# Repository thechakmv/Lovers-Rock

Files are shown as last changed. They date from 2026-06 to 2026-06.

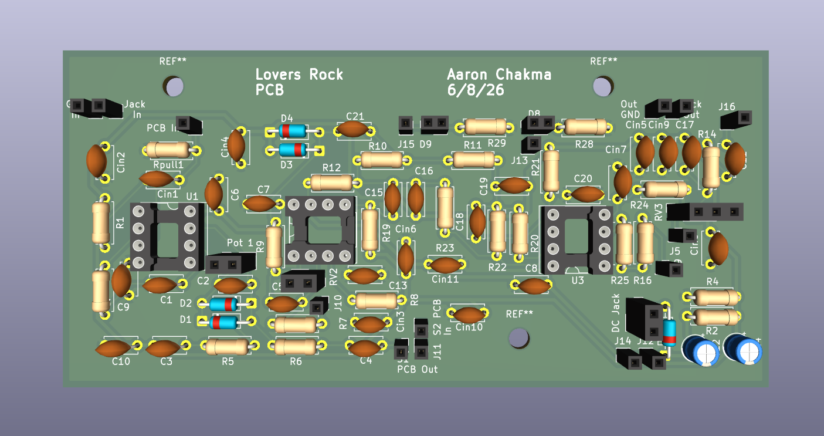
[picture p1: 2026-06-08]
images/kicad_3d.png

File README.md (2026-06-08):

# Dual-Stage Overdrive & Distortion Guitar Pedal

I created analog guitar effects pedal with two independent, switchable gain stageto achieve classic Thrash metal rhythm and lead tones: a soft-clipping overdrive with a **mid-boost** (+6 dB at 800 Hz) and a hard-clipping distortion with a **mid-scoop** (−6 to −10 dB across 400–800 Hz). The Pedal features a single-knob volume control, and gain controls for each stage as well. Each stage has true-bypass switching, so the two can run independently or be cascaded for stacked high-gain lead tones.

## Highlights

- Designed and simulated in LTSpice
- Two-stage analog signal chain built around TL072 op-amps
- True-bypass per stage via 3PDT footswitches, both stages can be activated simultaneously for cascaded gain
- Gyrator filter network for scooped voicings on distortion
- Single 9 V DC supply, ~15 mA total current draw
- PCB layout in KiCad with attention to signal integrity, and inter-stage isolation

## Signal Flow

```
                                                         
 Guitar ─> Input ─┬─> OD Stage ──┬─> Distortion ───> Tone ──┬> Volume ─> Output ─> Amp
          Buffer  │   (soft clip,│   (hard clip + (LPF)     │
          (TL072) │   mid-boost) │   Twin-T scoop)          │
                  │              │                          │
                  ▼              ▼                          ▼
                SW1 3PDT        SW2 3PDT                    Always
                true bypass     true bypass                 on signal path
```

When both switches are engaged, the OD output feeds the distortion stage input, producing a mid boosted overdrive. Each stage can also run alone for classic rock overdrive or for chuggy thrash metal rhythm tones.

## Design Specifications

| Parameter | Value |
|---|---|
| Supply | 9 V DC, center-negative, ~30 mA |
| OD Specs | peak at ~800Hz |
| OD clipping | Soft, symmetric, ±0.6 V (1N4148 anti-parallel in feedback) |
| Distortion Specs | Notch at around 800Hz |
| Distortion clipping | Hard, symmetric, ±0.6 V (1N4148 to Vref) |

## Design Philosophy

Thrash metal dictates that you have wo pedals. One Distortion, and one overdrive. For my pedal I wanted to combine these two topologies into one pedal. This design uses two intentionally distinct gain stages whose characters complement each other when cascaded overdrive to distortion.

The **overdrive stage** is a Tube Screamer-derived non-inverting topology with silicon diodes inside the feedback loop. The feedback RC network forms a band-pass response: lows roll off below 720 Hz and highs roll off above ~6 kHz at maximum gain. Inside the band the gradual diode conduction produces soft clipping that preserves the dry signal underneath the saturation, giving the characteristic transparent overdrive sound.

The **distortion stage** uses an inverting topology with diodes clamping the op-amp output directly to the Vref node. This produces hard, square-wave clipping rich in odd harmonics. The clipped signal then feeds a dual gyrator bandpass filter with peaks at 150 Hz, and 3.3KHz, carving out the middle frequencies by boosting the low and high frquencies.

The two stages are independently switchable: OD alone for classic rock, distortion alone for chunky rhythm, and both stacked for full-spectrum lead tones.

## Repository Structure

```
├── ltspice/
│   ├── Draft2.asc         
├── kicad/
│   ├── Lovers Rock.kicad_pro             Project file
│   ├── Lovers Rock.kicad_sch             Schematic
│   ├── Lovers Rock.kicad_pcb             Board layout
│   └── gerbers/                    Fabrication output (zipped Gerbers + drill)
└── images/
    ├──        
```

## Tools

**Software:** LTSpice, KiCad 10

**Test equipment:** multimeter, soldering iron, electrical components (caps, resistors etc.)

## Build Process

1. **Simulate.** Run AC and transient analyses in LTSpice for each stage. Verify gain curves, clipping shape, and Vref stability under load. Use `.step` to sweep gain pot values and see the response variation across the control range.

2. **Prototype.** Build stage-by-stage with bench power. tune by ear — swap diodes (Si vs. LED vs. asymmetric), tweak the frequencies, and adjust the gain ranges.

3. **PCB.** Re-capture the validated schematic in KiCad, assign through-hole footprints, lay out the board with the external component sockets neat their enclosure mounts. Generate Gerbers and fabricate via JLCPCB.

**TBD:**

1. **Verify.** Measure assembled pedal's frequency response and FFT using spectrul analyzer to compare against simulation predictions.
2. Order the PCBS, and prepare for final assembly

## Design Issues Encountered (and Fixed)

Some that problems came up during simulation and breadboarding that are worth documenting:

**Ridiculous power supply noise.** The power supply was being unrully, and I added bypass capacitors to each power trace to help mitigate the noise I was experiencing.

**Vref instability under heavy distortion.** The hard-clipping diodes were pumping current pulses into the Vref node, dragging it from 4.5 V down toward 1 V during the clipping phase. I Fixed it by adding a 1 kΩ series resistor between the distortion op-amp's output and the diode pair, limiting peak diode current and preserving Vref node.

**High-frequency oscillation at high gain.** The TL072 stages were prone to oscillation when driving purely capacitive loads, so I fixed it by adding a 470 Ω series isolation resistor between each op-amp output and its capacitive load.

## Skills Demonstrated

- Analog circuit design with op-amps
- Frequency-response shaping via active gyrator filter networks
- Soft-clipping vs. hard-clipping topology selection and harmonic analysis
- Single-supply audio biasing: Vref generation, AC coupling, bypass strategy
- SPICE simulation: AC sweep, transient analysis, FFT, parametric stepping
- PCB layout for analog audio: ground topology, decoupling, inter-stage isolation

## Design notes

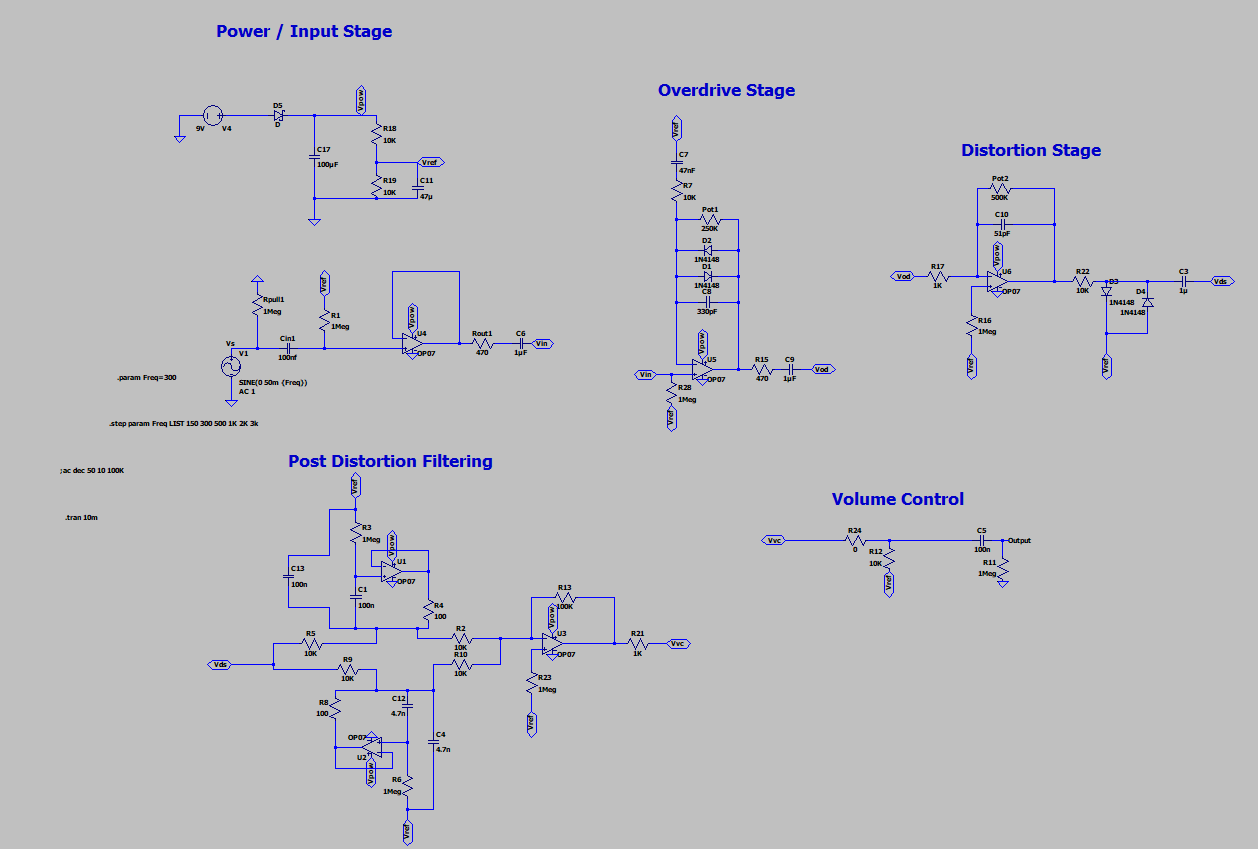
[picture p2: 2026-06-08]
images/spice_schematic.png

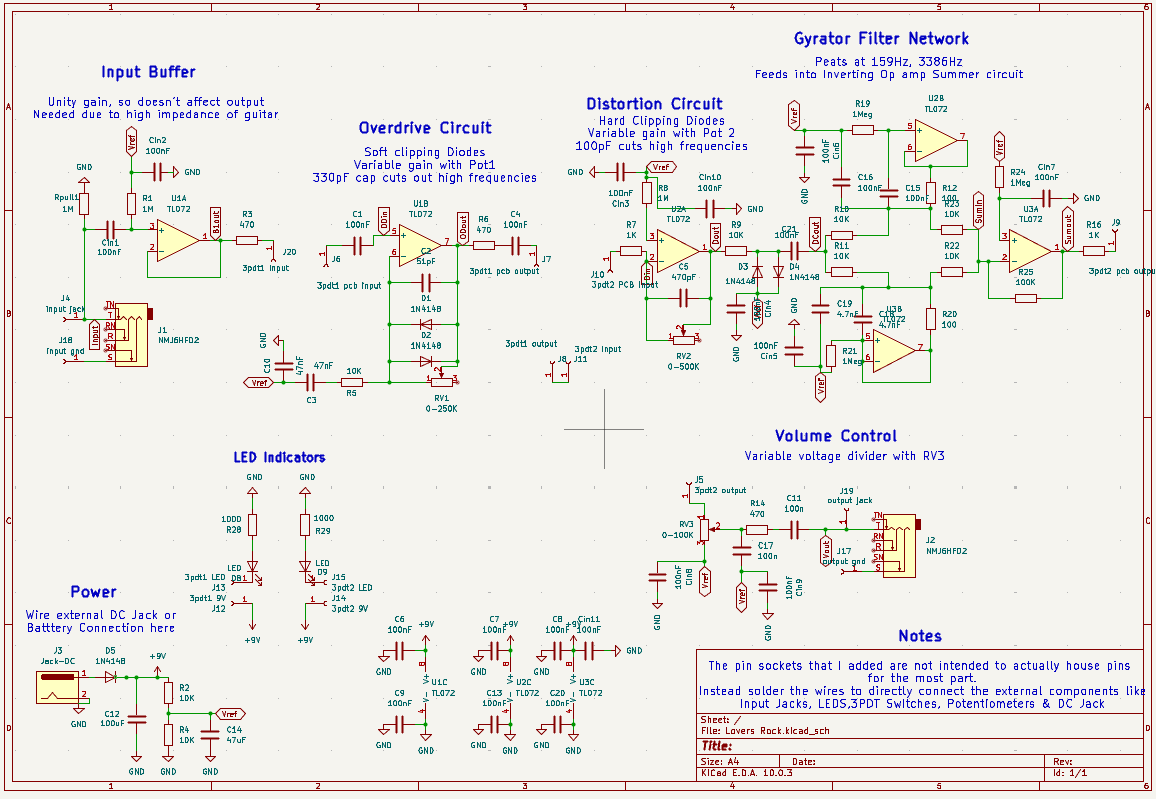
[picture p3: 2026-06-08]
images/kicad_schematic.png

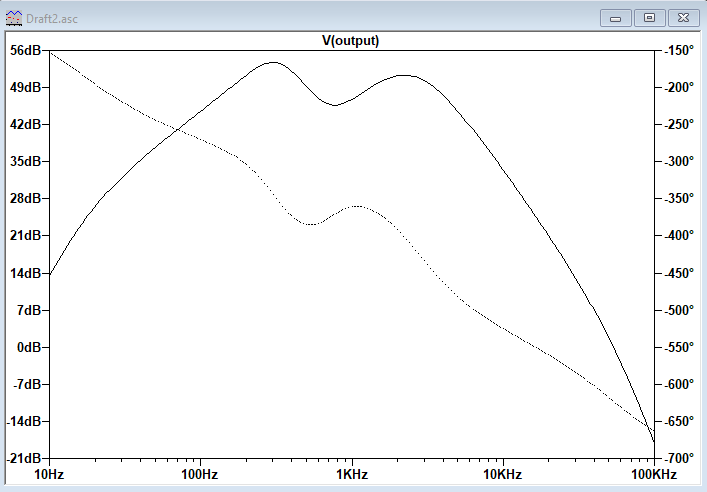
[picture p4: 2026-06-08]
images/ds_bode.png

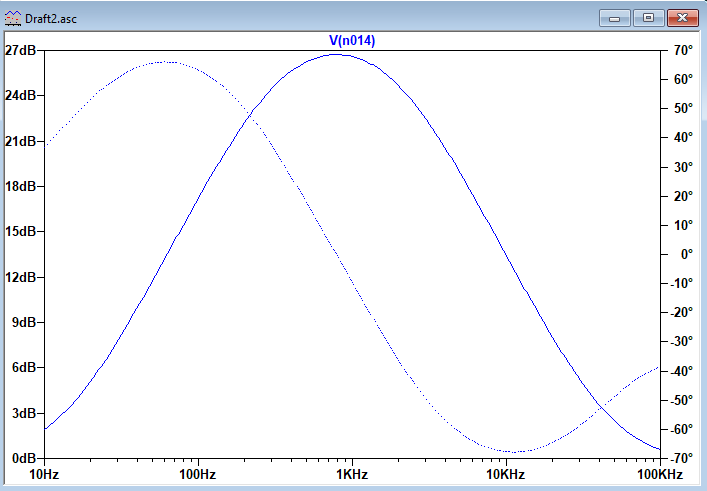
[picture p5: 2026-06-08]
images/od_bode.png

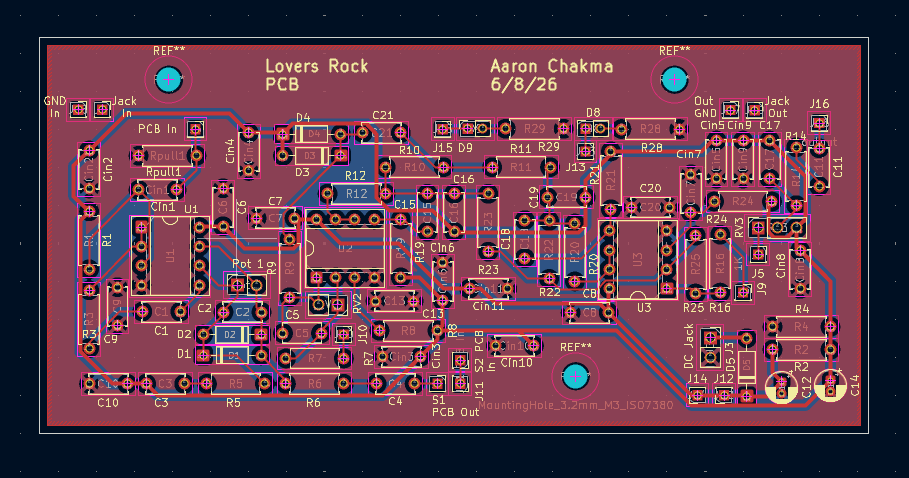
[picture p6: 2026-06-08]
images/kicad_layout.png

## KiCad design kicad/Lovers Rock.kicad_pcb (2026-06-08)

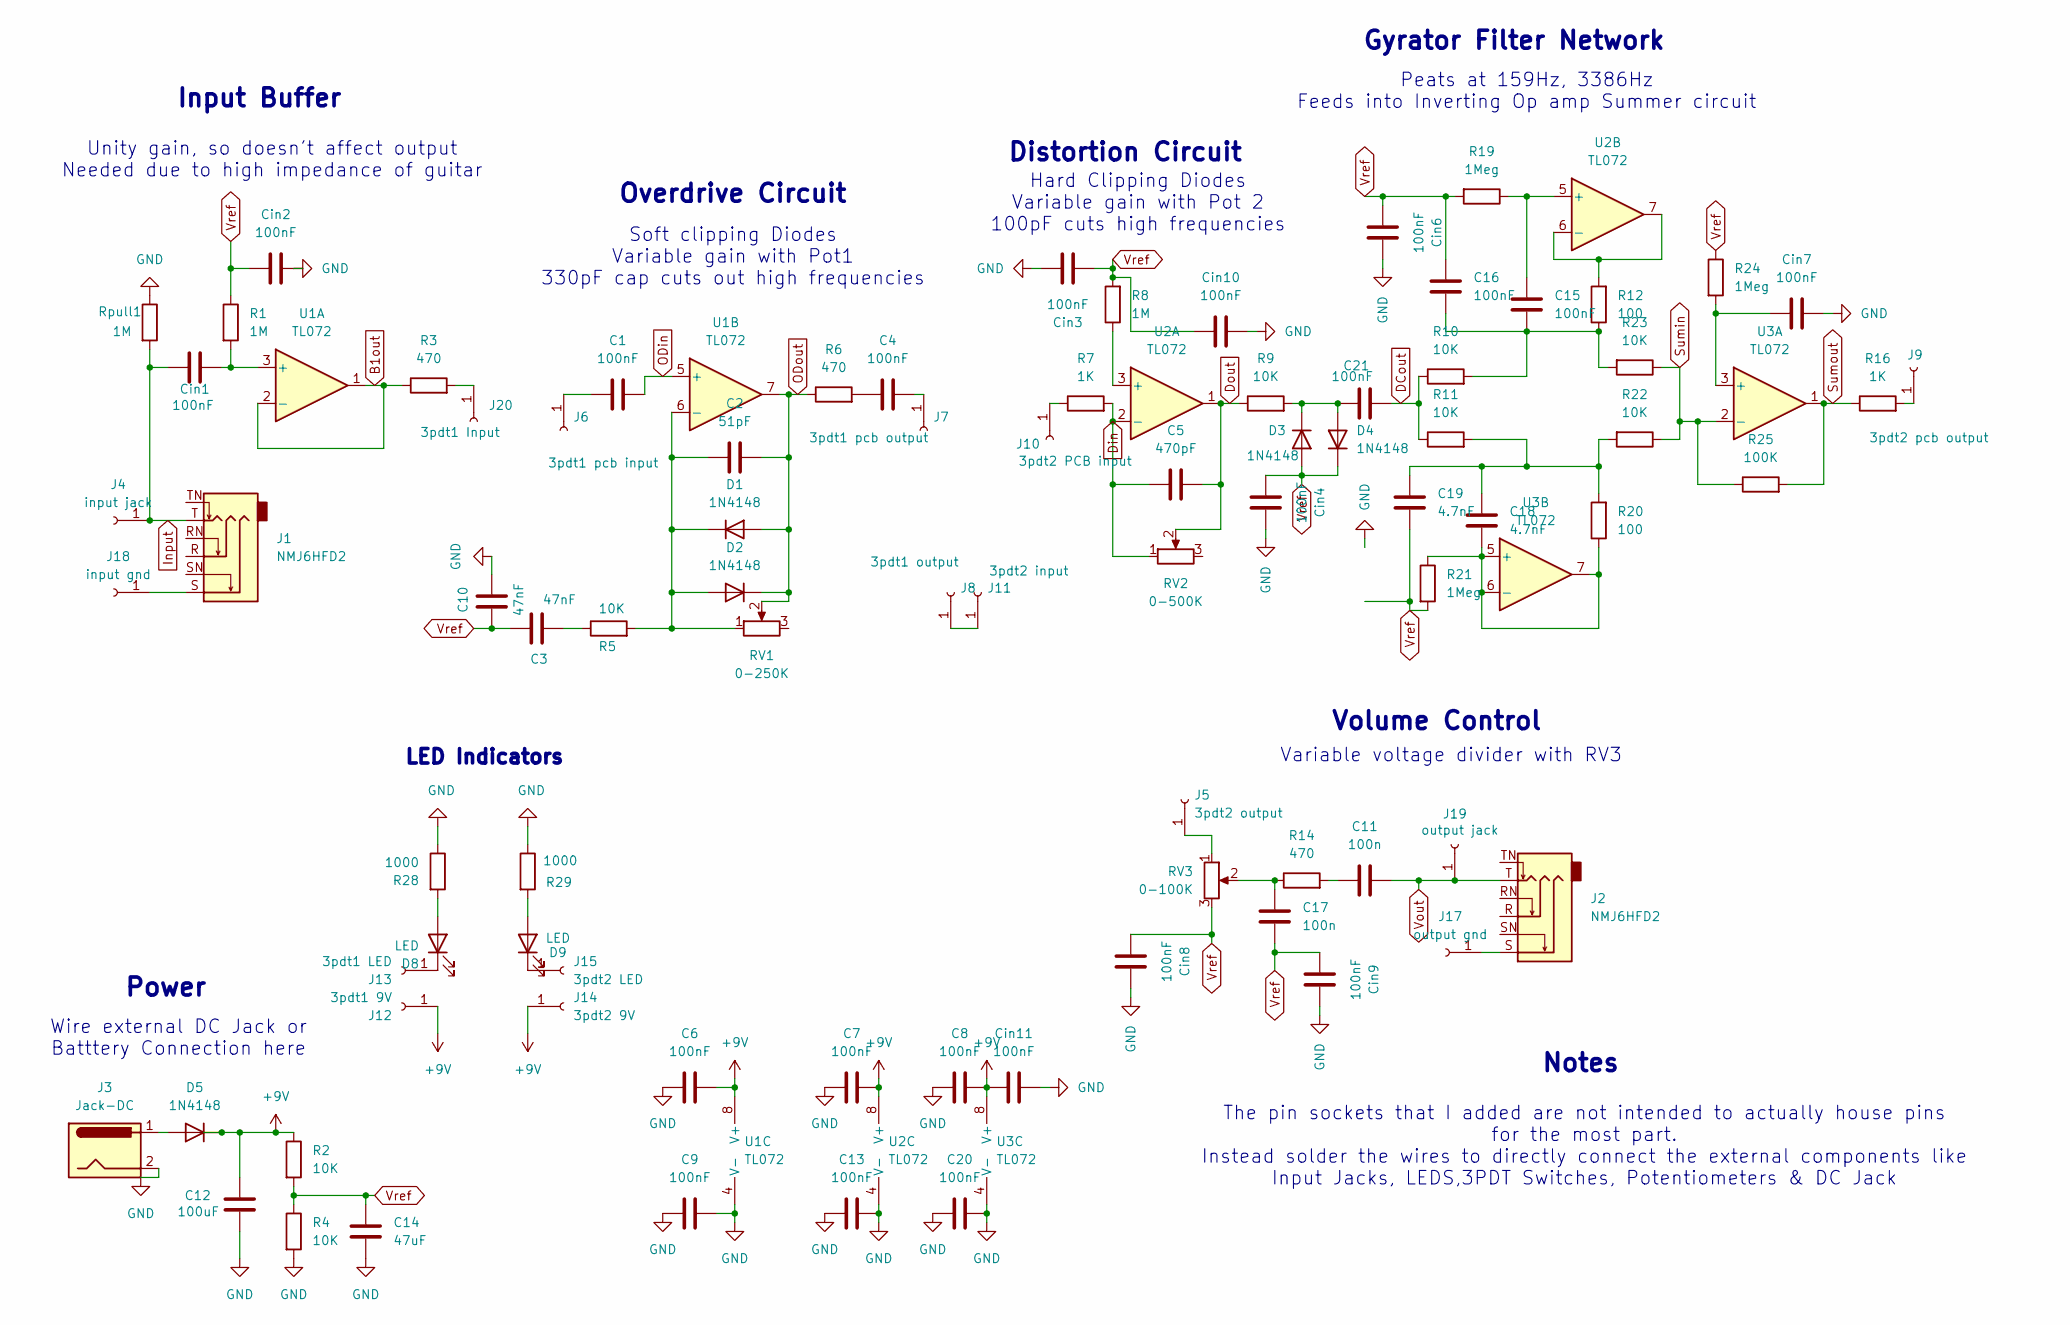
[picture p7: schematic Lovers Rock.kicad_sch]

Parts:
C1, C4, C6, C7, C8, C9, C13, C15, C16, C20, C21: 100nF; C_Disc_D5.0mm_W2.5mm_P5.00mm
C2: 51pF; C_Disc_D5.0mm_W2.5mm_P5.00mm
C3, C10: 47nF; C_Disc_D5.0mm_W2.5mm_P5.00mm
C5: 470pF; C_Disc_D5.0mm_W2.5mm_P5.00mm
C11, C17: 100n; C_Disc_D5.0mm_W2.5mm_P5.00mm
C12: 100uF; CP_Radial_D4.0mm_P1.50mm
C14: 47uF; CP_Radial_D4.0mm_P1.50mm
C18, C19: 4.7nF; C_Disc_D5.0mm_W2.5mm_P5.00mm
Cin1, Cin2, Cin3, Cin4, Cin6, Cin7, Cin8, Cin9, Cin10, Cin11: 100nF; C_Disc_D5.0mm_W2.5mm_P5.00mm
D1, D2, D3, D4, D5: 1N4148; D_DO-35_SOD27_P7.62mm_Horizontal
D8, D9: LED; PinSocket_1x02_P2.00mm_Vertical
J1, J2: NMJ6HFD2; Jack_6.35mm_Neutrik_NMJ6HFD2_Horizontal
J3: Jack-DC; PinSocket_1x02_P2.54mm_Vertical
J4: input jack; PinSocket_1x01_P2.00mm_Vertical
J5: 3pdt2 output; PinSocket_1x01_P2.00mm_Vertical
J6: 3pdt1 pcb input; PinSocket_1x01_P2.00mm_Vertical
J7: 3pdt1 pcb output; PinSocket_1x01_P2.00mm_Vertical
J8: 3pdt1 output; PinSocket_1x01_P2.00mm_Vertical
J9: 3pdt2 pcb output; PinSocket_1x01_P2.00mm_Vertical
J10: 3pdt2 PCB input; PinSocket_1x01_P2.00mm_Vertical
J11: 3pdt2 input; PinSocket_1x01_P2.00mm_Vertical
J12: 3pdt1 9V; PinSocket_1x01_P2.00mm_Vertical
J13: 3pdt1 LED; PinSocket_1x01_P2.00mm_Vertical
J14: 3pdt2 9V; PinSocket_1x01_P2.00mm_Vertical
J15: 3pdt2 LED; PinSocket_1x01_P2.00mm_Vertical
J17: output gnd; PinSocket_1x01_P2.00mm_Vertical
J18: input gnd; PinSocket_1x01_P2.00mm_Vertical
J19: output jack; PinSocket_1x01_P2.00mm_Vertical
J20: 3pdt1 Input; PinSocket_1x01_P2.00mm_Vertical
R1, R8: 1M; R_Axial_DIN0207_L6.3mm_D2.5mm_P7.62mm_Horizontal
R2, R4, R5, R9, R10, R11, R22, R23: 10K; R_Axial_DIN0207_L6.3mm_D2.5mm_P7.62mm_Horizontal
R3, R6, R14: 470; R_Axial_DIN0207_L6.3mm_D2.5mm_P7.62mm_Horizontal
R7, R16: 1K; R_Axial_DIN0207_L6.3mm_D2.5mm_P7.62mm_Horizontal
R12, R20: 100; R_Axial_DIN0207_L6.3mm_D2.5mm_P7.62mm_Horizontal
R19, R21, R24: 1Meg; R_Axial_DIN0207_L6.3mm_D2.5mm_P7.62mm_Horizontal
R25: 100K; R_Axial_DIN0207_L6.3mm_D2.5mm_P7.62mm_Horizontal
R28, R29: 1000; R_Axial_DIN0207_L6.3mm_D2.5mm_P7.62mm_Horizontal
RV1: 0-250K; PinSocket_1x02_P2.54mm_Vertical
RV2: 0-500K; PinSocket_1x02_P2.54mm_Vertical
RV3: 0-100K; PinSocket_1x03_P2.54mm_Vertical
Rpull1: 1M; R_Axial_DIN0207_L6.3mm_D2.5mm_P7.62mm_Horizontal
U1, U2, U3: TL072; DIP-8_W7.62mm_Socket

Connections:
+9V: C6.2, C7.2, C8.2, C12.1, Cin11.1, D5.1 (K), J12.1 (Pin_1_1), J14.1 (Pin_1_1), R2.1, U1.8 (V+), U2.8 (V+), U3.8 (V+)
B1out: R3.1, U1.1, U1.2 (-)
DCout: C21.1, R10.1, R11.1
Din: C5.1, R7.2, RV2.1, U2.2 (-)
Dout: C5.2, R9.1, RV2.2, U2.1
GND: C6.1, C7.1, C8.1, C9.1, C9.2, C10.2, C12.2, C13.1, C13.2, C14.2, C20.1, C20.2, Cin2.2, Cin3.2, Cin4.2, Cin6.2, Cin7.2, Cin8.2, Cin9.2, Cin10.2, Cin11.2, J3.2, R4.2, R28.1, R29.1, Rpull1.1, U1.4 (V-), U2.4 (V-), U3.4 (V-); also elsewhere on the board
Input: Cin1.1, J1.T, J4.1, Rpull1.2
unnamed: C3.2, R5.1
unnamed: C4.1, R6.2
unnamed: C11.2, R14.2
unnamed: C15.1, C16.1, R10.2, R12.1, R23.2
unnamed: C17.1, R14.1, RV3.2
unnamed: C18.2, C19.2, R11.2, R20.2, R22.2
unnamed: C2.1, D1.1 (K), D2.2 (A), R5.2, RV1.1, U1.6 (-)
unnamed: C21.2, D3.1 (K), D4.2 (A), R9.2
unnamed: D5.2 (A), J3.1
unnamed: D8.2 (A), R28.2
unnamed: D8.1 (K), J13.1 (Pin_1_1)
unnamed: D9.2 (A), R29.2
unnamed: D9.1 (K), J15.1 (Pin_1_1)
unnamed: J5.1 (Pin_1_1), RV3.1
unnamed: C1.1, J6.1 (Pin_1_1)
unnamed: C4.2, J7.1 (Pin_1_1)
unnamed: J9.1 (Pin_1_1), R16.2
unnamed: J10.1 (Pin_1_1), R7.1
unnamed: J8.1 (Pin_1_1), J11.1 (Pin_1_1)
unnamed: J2.S, J17.1 (Pin_1_1)
unnamed: J1.S, J18.1 (Pin_1_1)
unnamed: J20.1 (Pin_1_1), R3.2
unnamed: Cin1.2, R1.2, U1.3 (+)
unnamed: R8.1, U2.3 (+)
unnamed: C15.2, R19.1, U2.5 (+)
unnamed: R12.2, U2.6 (-), U2.7
unnamed: Cin7.1, R24.2, U3.3 (+)
unnamed: C18.1, R20.1, R21.1, U3.5 (+), U3.6 (-), U3.7
ODin: C1.2, U1.5 (+)
ODout: C2.2, D1.2 (A), D2.1 (K), R6.1, RV1.2, U1.7
Sumin: R22.1, R23.1, R25.1, U3.2 (-)
Sumout: R16.1, R25.2, U3.1
Vout: C11.1, J2.T, J19.1 (Pin_1_1)
Vref: C3.1, C10.1, C14.1, C16.2, C17.2, C19.1, Cin2.1, Cin3.1, Cin4.1, Cin6.1, Cin8.1, Cin9.1, Cin10.1, D3.2 (A), D4.1 (K), R1.1, R2.2, R4.1, R8.2, R19.2, R21.2, R24.1, RV3.3; also elsewhere on the board

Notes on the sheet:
Hard Clipping Diodes Variable gain with Pot 2 100pF cuts high frequencies
Peats at 159Hz, 3386Hz Feeds into Inverting Op amp Summer circuit
Unity gain, so doesn't affect output Needed due to high impedance of guitar
Variable voltage divider with RV3
LED Indicators
Notes
The pin sockets that I added are not intended to actually house pins for the most part. Instead solder the wires to directly connect the external components like Input Jacks, LEDS,3PDT Switches, Potentiometers & DC Jack
Wire external DC Jack or Batttery Connection here
Input Buffer
Soft clipping Diodes Variable gain with Pot1 330pF cap cuts out high frequencies
Overdrive Circuit
Volume Control
Power
Distortion Circuit
Gyrator Filter Network

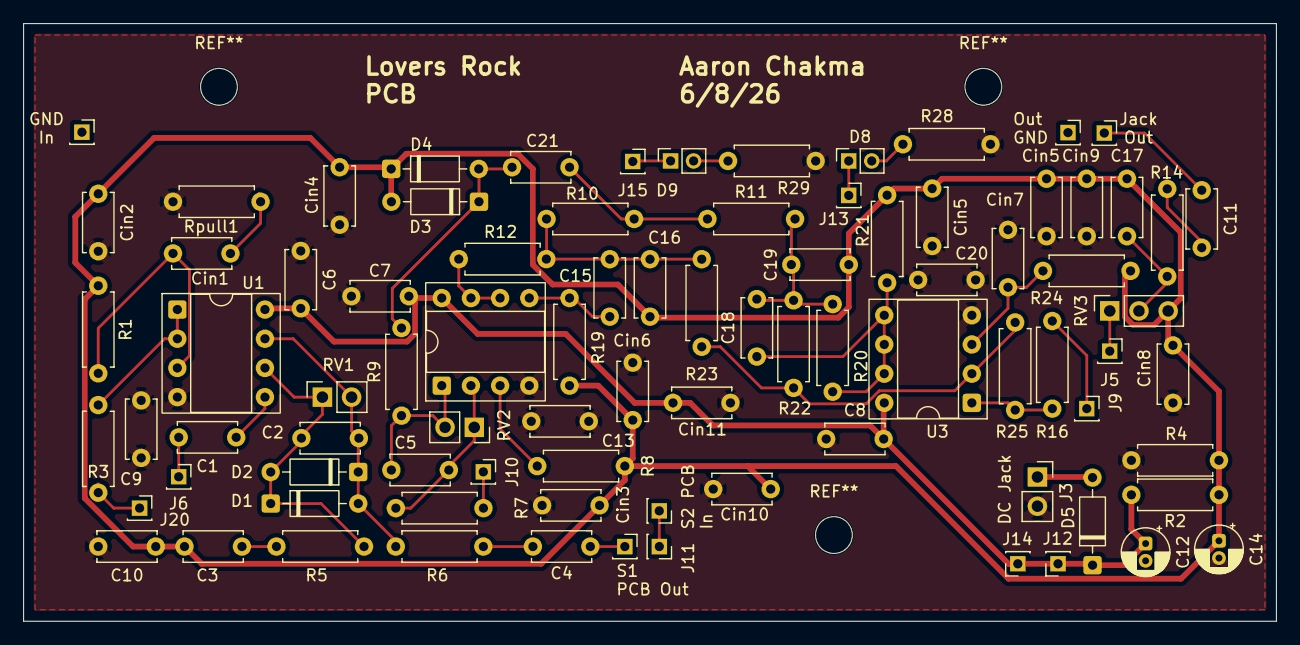
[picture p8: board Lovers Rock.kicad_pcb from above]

Board: 2 copper layers, 109.0 x 52.0 mm, 86 parts (0 on the bottom side), 39 nets.

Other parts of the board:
Cin5, Cin5#2: 100nF; C_Disc_D5.0mm_W2.5mm_P5.00mm

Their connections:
GND: Cin5.2, Cin5#2.1; also elsewhere on the board
Vref: Cin5.1, Cin5#2.2; also elsewhere on the board
